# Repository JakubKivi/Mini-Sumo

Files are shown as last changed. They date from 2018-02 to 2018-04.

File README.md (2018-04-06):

# Mini-Sumo
First really project by CałkaCompany+

Oznaczenia wyjść i wejść w kodzie:

| numer wyjścia | arduino | zmienna w kodzie  | opis |
| ---  |---| ---  | ---  |
| 1 |  PWM/D3 | `floorBR` | Czujnik podłoża prawy tylny  |
| 2 | D4 | `floorFR` | Czujnik podłoża prawy przedni |
| 3\5\21 | GND | `-` | Uziemienie |
| 4\6 | VCC | `-` | Zasilanie |
| 9 |  PWM/D5 | `PWMA` | PWM dla silnika A |
| 10 |  PWM/D6 | `AIN2` | Wejście sterujące |
| 11 | D7 | `AIN1` | Wejście sterujące |
| 12 | D8 | `STBY` | |
| 13 | D9 | `BIN1` | Wejście sterujące |
| 14 | D10  | `BIN2` | Wejście sterujące |
| 15 | PWM/D11 | `PWMB` | PWM dla silnika B |
| 16 | D12  | `-` | |
| 17 | D13  | `sensorFL` | Czujnik odległości lewy przedni |
| 23 | A0 | `sensorFR` | Czujnik odległości prawy przedni|
| 24 | A1 | `sensorF` | Czujnik odległości przedni |
| 25 | A2 | `sensorBL` | Czujnik odległości prawy tylny  |
| 26 | A3 | `sensorB` | Czujnik odległości tylni |
| 27 | A4 | `-` | |
| 28 | A5 | `-` | |
| 30 |  D0/RX  | `sensorBR` |  Czujnik odległości prawy tylni |
| 31 |  D1/TX  | `floorBL` | Czujnik podłoża lewy tylny |
| 32 | D2 | `floorFL` |  Czujnik podłoża lewy przedni |

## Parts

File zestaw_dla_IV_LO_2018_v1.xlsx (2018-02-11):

typ | model | obrazek/ zdjęcie | sklep | opis | masa (g) | zagrożenie zużycia | ilość min | ilość max | cena | cena łącznie min | cena łącznie max
Komparator analogowy | Komparator analogowy LM339 - SMD |  | https://botland.com.pl/uklady-scalone-komparatory/75-komparator-analogowy-lm339-smd.html | Napięcie zasilania: 36 V lub +/- 18 V Napięcie wejściowe: -0,3 V do 36 V Obudowa: SO14 | - | wysokie | 1 | 3 | 0.50 zł | 0.50 zł | 1.50 zł
Potencjometr | Potencjometr 47kΩ leżący - SMD |  | https://botland.com.pl/potencjometry/872-potencjometr-47k-lezacy-smd.html | Potencjometr: montażowy, węglowy, leżący. Rezystancja: 47 kΩ Moc: 100 mW. Obudowa SMD. Typ: potencjometru montażowy, węglowy Moc: 100 mW Rezystancja: 47 kΩ Tolerancja: ±2 0% Charakterystyka: liniowa Wymiary korpusu: 6.5 x 6.5 x 3.6 mm Temperatura pracy: -25 do 70 st. C Kąt obrotu elektryczny: 215 ±20 st. Moment obrotowy: <2 Ncm Napięcie pracy: maks. 100 V DC Trwałość mechaniczna: 1000 cykli Standard potencjometru: 6 mm | - | niskie | 4 | 4 | 1.20 zł | 4.80 zł | 4.80 zł
Wtyk goldpin | Wtyk goldpin 1x40 prosty raster 2,54mm |  | https://botland.com.pl/gniazda-szpilkowe-goldpin/192-wtyk-goldpin-1x40-prosty-raster-254-mm.html | Listwa goldpin męska 1x40, raster 2,54 mm | - | niskie | 1 | 1 | 0.70 zł | 0.70 zł | 0.70 zł
Wtyk goldpin | Wtyk goldpin 1x40 kątowy raster 2,54mm |  | https://botland.com.pl/gniazda-szpilkowe-goldpin/205-wtyk-goldpin-1x40-katowe.html | Listwa goldpin męska 1x40, raster 2,54 mm. | - | niskie | 1 | 1 | 0.70 zł | 0.70 zł | 0.70 zł
Wtyk goldpin | Wtyk goldpin 1x40 prosty raster 2,54mm - żółty |  | https://botland.com.pl/gniazda-szpilkowe-goldpin/4167-wtyk-goldpin-1x40-prosty-raster-254-mm-zolty.html | Wtyk goldpin męski 1x40, raster 2,54 mm. Kolor żółty. | - | niskie | 1 | 1 | 0.80 zł | 0.80 zł | 0.80 zł
Wtyk goldpin | Wtyk goldpin 1x40 prosty raster 2,54mm - niebieski |  | https://botland.com.pl/gniazda-szpilkowe-goldpin/4168-wtyk-goldpin-1x40-prosty-raster-254-mm-niebieski.html | Wtyk goldpin męski 1x40, raster 2,54 mm. Kolor niebieski. | - | niske | 1 | 1 | 0.80 zł | 0.80 zł | 0.80 zł
Wtyk goldpin | Wtyk goldpin 1x40 prosty raster 2,54mm - czerwony |  | https://botland.com.pl/gniazda-szpilkowe-goldpin/4165-wtyk-goldpin-1x40-prosty-raster-254-mm-czerwony-.html | Wtyk goldpin męski 1x40, raster 2,54 mm. Kolor czerwony. | - | niske | 1 | 1 | 0.80 zł | 0.80 zł | 0.80 zł
Zestaw diod LED | Zestaw diod LED SMD 0603 - 30 szt. |  | https://botland.com.pl/zestawy-diod-led/1456-zestaw-diod-led-smd-0603-30-szt.html | W zestawie po 10 sztuk diod zielonych, żółtych i czerwonych. Zestaw 30 diod w obudowie lutowanej powierzchniowo SMD 0603. W pakiecie znajduje się: 10 diod czerwonych 10 diod żółtych 10 diod zielonych Parametry diody żółtej: Kolor: żółty Długość emitowanej fali: ok. 590 nm Jasność: 30 mcd Kąt świecenia: 140 ° Obudowa: SMD 0603 Parametry pracy: Prąd If: 20 mA Napięcie Vf: 2,0 V Parametry diody czerwonej: Kolor: czerwony Długość emitowanej fali: 625 nm Jasność: 40 mcd Kąt świecenia: 140 ° Obudowa: SMD 0603 Parametry pracy: Prąd If: 20 mA Napięcie Vf: 2,0 V Parametry diody zielonej: Kolor: zielony Długość emitowanej fali: ok. 575 nm Jasność: 30 mcd Kąt świecenia: 140 ° Obudowa: SMD 0603 Parametry pracy: Prąd If: 20 mA Napięcie Vf: 2,0 V | - | niskie | 1 | 1 | 4.90 zł | 4.90 zł | 4.90 zł
Stabilizator | Stabilizator 5V 7805CD2T - SMD TO263 |  | https://botland.com.pl/regulatory-napiecia/756-stabilizator-5v-lm7805-smd.html | Stabilizator wykorzystywany do zasilania układów logicznych zasilanych napięciem 5V. Maksymalny prąd wyjściowy to 1A. Obudowa TO263 (D2PAK). Napięcie wyjściowe: 5V Maksymalny prąd wyjściowy: 1A Maksymalne napięcie wejściowe: 35V Obudowa: TO263 (D2PAK) | - | wysokie | 1 | 3 | 1.30 zł | 1.30 zł | 3.90 zł
Stabilizator | Stabilizator 5V L7805CV - THT TO220 |  | https://botland.com.pl/regulatory-napiecia/3092-stabilizator-5v-l7805cv-tht-to220.html | Stabilizator wykorzystywany do zasilania układów logicznych zasilanych napięciem 5 V. Maksymalny prąd wyjściowy to 1,5 A. Symbol: LM7805 Napięcie wyjściowe: 5 V ( z dokładnością do 2 %) Maksymalny prąd wyjściowy: 1,5 A Maksymalne napięcie wejściowe: 35 V Obudowa: TO-220 | - | wysokie | 1 | 3 | 0.90 zł | 0.90 zł | 2.70 zł
Kondensator ceramiczny | Zestaw kondensatorów ceramicznych 0805 190szt. |  | http://allegro.pl/zestaw-kondensatorow-ceramicznych-0805-190szt-i6819067595.html | Zestaw kondensatorów SMD 0805. W skład zestawu wchodzi 19 wartości w listkach po 10 sztuk każdej od 22 pF do 1000 nF | - | niskie | 1 | 1 | 11.99 zł | 11.99 zł | 11.99 zł
Mikrokontroler AVR | Mikrokontroler AVR - ATmega328P-AU SMD |  | https://botland.com.pl/avr-w-obudowie-smd/1836-mikrokontroler-avr-atmega328p-au-smd.html | Mikrokontroler z rodziny AVR firmy Atmel w obudowie lutowanej powierzchniowo (SMD. Został wykorzystany w popularnym module Arduino Pro.)Zasilanie: 1,8 V - 5,5 V Taktowanie: do 20MHz Pamięć Flash: 32KB 23 linie wyjścia/wejścia Dwa 8-bitowe liczniki Jeden 16-bitowy licznik 6 kanałów PWM 6 kanałów 10-bitowego przetwornika analogowo-cyfrowego Sprzętowe interfejsy komunikacyjne: USART, SPI, TWI (I2C) Obudowa SMD - TQF P32 | - | wysokie | 1 | 3 | 8.90 zł | 8.90 zł | 26.70 zł
Mikrokontroler AVR | Mikrokontroler AVR - ATmega328P-PU DIP |  | https://botland.com.pl/avr-tht-dip/1264-mikrokontroler-avr-atmega328p-pu-dip.html | Mikrokontroler z rodziny AVR firmy Atmel w obudowie przewlekanej (DIP). Został wykorzystany w popularnym module Arduino Uno.Zasilanie: 1,8 V - 5,5 V Taktowanie: do 20 MHz Pamięć Flash: 32 KB 23 linie wyjścia/wejścia Dwa 8-bitowe liczniki Jeden 16-bitowy licznik 6 kanałów PWM 6 kanałów 10-bitowego przetwornika analogowo-cyfrowego Sprzętowe interfejsy komunikacyjne: USART, SPI, TWI (I2C) Obudowa DIP | - | wysokie | 1 | 3 | 10.90 zł | 10.90 zł | 32.70 zł
Podstawka do układów DIP 28 pin wąska - 5 szt. | Podstawka do układów DIP 28 pin wąska - 5 szt. |  | https://botland.com.pl/podstawki-pod-uklady-scalone/90-podstawka-do-ukladow-dip-28pin-waska-5szt.html | Podstawka pod układ scalony DIP 28. Cena za 5 sztuk. | - | niskie | 1 | 1 | 2 zł | 2.00 zł | 2.00 zł
rezystory | Zestaw rezystorów SMD 0805 - 1500szt. |  | https://botland.com.pl/zestawy-rezystorow/536-zestaw-rezystorow-smd-0805-2500-szt.html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 | Zbiór 30 popularnych wartości rezystorów o tolerancji 5 % w obudowach SMD 0805, przydatnych w warsztacie zarówno robotyka jak i elektronika. Rezystory są zapakowane w osobne, opisane torebki strunowe. Całość znajduje się w kartonowym pudełku, ułatwiającym przechowywanie. | - | niskie | 1 | 1 | 23.90 zł | 23.90 zł | 23.90 zł
czujniki odległości | Pololu - cyfrowy czujnik odległości IR 38kHz - 60cm |  | https://botland.com.pl/cyfrowe-czujniki-odleglosci/7622-pololu-cyfrowy-czujnik-odleglosci-ir-38khz-60cm.html | Napięcie zasilania: od 3,3 V do 5 V Pobór prądu: 16 mA Układ: TSSP77038 Częstotliwość próbkowania: 1 kHz Zasięg: do 60 cm Wymiary: 15 x 10 x 5 mm Masa: 0,6 g | - | średnie | 6 | 8 | 28.41 zł | 170.46 zł | 227.28 zł
Czujnik podłoża | Czujnik transoptor odbiciowy CNY70 |  | https://botland.com.pl/transoptory-odbiciowe/52-czujnik-transoptor-odbiciowy-cny70.html | Transoptor odbiciowy, stosowany np. do odróżniania krawędzi lub wykrywania linii. Wymiary obudowy to 7 x 7 x 6 mm, montaż przewlekany. Napięcie zasilania diody: 5 V Maksymalny prąd diody: 50 mA Maksymalne napięcie kolektor-emiter: 32 V Maksymalny prąd kolektora: 50 mA | - | średnie | 10 | 12 | 2.66 zł | 26.60 zł | 31.92 zł
silniki | Silnik Pololu MP 10:1 |  | https://botland.com.pl/medium-power-mp-/4063-silnik-pololu-mp-101.html | Napięcie zasilania:3 V - 9 V Prąd bez obciążenia (6 V):40 mA Prąd przy zatrzymanym wale (6 V):700 mA Prędkość bez obciążenia (6 V):2200 obr/min Moment obrotowy (6 V):0,2 kg*cm (0,010 Nm) Przełożenie:9.96:1 Średnica wału:3 mm Wymiary korpusu:24 x 10 x 12 mm Masa:10 g Obustronny wał:NIE | 40 | wysokie | 4 | 6 | 61.66 zł | 246.64 zł | 369.96 zł
sterownik silników | TB6612FNG - dwukanałowy sterownik silników |  | https://botland.com.pl/sterowniki-silnikow-dc/495-tb6612fng-dwukanalowy-sterownik-silnikow-.html | Dwukanałowy mostek H. Ciągły prąd na kanał 1,2 A chwilowy do 3,2 A. Napięcie zasilania do 15 V. Obudowa SSOP-24 (SMD).Maksymalne napięcie zasilania silników: 4,5 - 15 V Prąd ciągły 1,2 A Prąd chwilowy: 3,2 A Tryb niskiego poboru prądu (Standby) Możliwość zmiany kierunku obrotów silnika Możliwość szybkiego zatrzymania silnika Obudowa: SMD SSOP24 Kanały sterownika można połączyć aby otrzymać większą wydajność prądową | - | wysokie | 1 | 3 | 8.90 zł | 8.90 zł | 26.70 zł
akumulator | Pakiet Li-Pol Dualsky 800mAh 25C 2S 7.4V ECO-S |  | https://botland.com.pl/akumulatory-li-pol-2s-74v-/2393-pakiet-lipol-dualsky-800mah-25c-2s-74v-eco-s.html | Wydajny akumulator litowo-polimerowy Dualsky. Prąd rozładowania: ciągły 25 C (20 A). Wymiary 66 x 26 x 13,5 mm. Masa: 43 g.Parametry Dwa ogniwa (2S) Li-pol Producent: Dualsky, seria ES Napięcie nominalne: 7,4 V Pojemność: 800 mAh Prąd rozładowania ciągły: 25 C (20A) Wyjście balansera Przewody: 20AWG Zamontowany konektor - wtyk JST Wymiary: 66 x 26 x 13,5 mm Masa: 43 g | 43 | wysokie | 2 | 3 | 24.90 zł | 49.80 zł | 74.70 zł
Przewody połączeniowe | Przewody połączeniowe żeńsko-męskie 20cm - 40szt |  | https://botland.com.pl/przewody-polaczeniowe/1067-przewody-polaczeniowe-zesko-meskie-20cm-40szt.html | Zestaw zawiera 40 szt. różnokolorowych przewodów połączeniowych o długości 20 cm zakończonych z jednej strony złączem żeńskim, z drugiej końcówką męska.Zestaw zawiera 40 szt różnokolorowych przewodów połączeniowych o długości 20 cm. Zakończone są z jednej strony złączem żeńskim, z drugiej końcówką męska. Przewody można rozdzielać na pojedyncze sztuki. Przewody doskonale nadają się do łączenia pól na płytkach stykowych i w zestawach (np.: Arduino lub STM32Discovery). Długość przewodu 20cm. | - | niskie | 1 | 1 | 5.99 zł | 5.99 zł | 5.99 zł
Przewody połączeniowe | Przewody połączeniowe męsko-męskie 20cm - 40szt. |  | https://botland.com.pl/przewody-polaczeniowe/1223-przewody-polaczeniowe-mesko-meskie-20cm-40szt.html | Zestaw zawiera 40 szt. różnokolorowych przewodów połączeniowych o długości 20 cm. Zakończone są z obu stron złączem męskim typu goldpin. Przewody można rozdzielać na pojedyncze sztuki. doskonale nadają się do łączenia pól na płytkach stykowychi zestawach uruchomieniowych (np. Arduino, STM32Discovery). Długość przewodu to 20 cm. | - | niskie | 1 | 1 | 5.95 zł | 5.95 zł | 5.95 zł
Kondensator elektrolityczny | Kondensator elektrolityczny 100uF/16V SMD - 5 szt. |  | https://botland.com.pl/kondensatory-/257-kondensator-elektrolityczny-100uf16v-smd-5-szt.html | Kondensator elektrolityczny SMD, pojemność: 100 uF, napięcie maksymalne: 16 V, temperatura pracy maksymalna: 85 °C. Cena za 5 szt. Pojemność: 100 uF Napięcie maksymalne: 16V Rozmiar: Ø 6,3 x 5,3 mm Tolerancja ±20 % Temperatura pracy: maks. 85°C | - | niskie | 1 | 1 | 2.50 zł | 2.50 zł | 2.50 zł
Rezonator kwarcowy | Rezonator kwarcowy 16MHz - UC49 - SMD - niski |  | https://botland.com.pl/rezonatory/308-rezonator-kwarcowy-16mhz-uc49-smd-niski.html |  | - | niskie | 2 | 2 | 0.80 zł | 1.60 zł | 1.60 zł
razem |  |  |  | RAZEM: |  |  |  |  |  | 592.33 zł | 865.49 zł

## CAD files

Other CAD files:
ZabawaKiviego.blend

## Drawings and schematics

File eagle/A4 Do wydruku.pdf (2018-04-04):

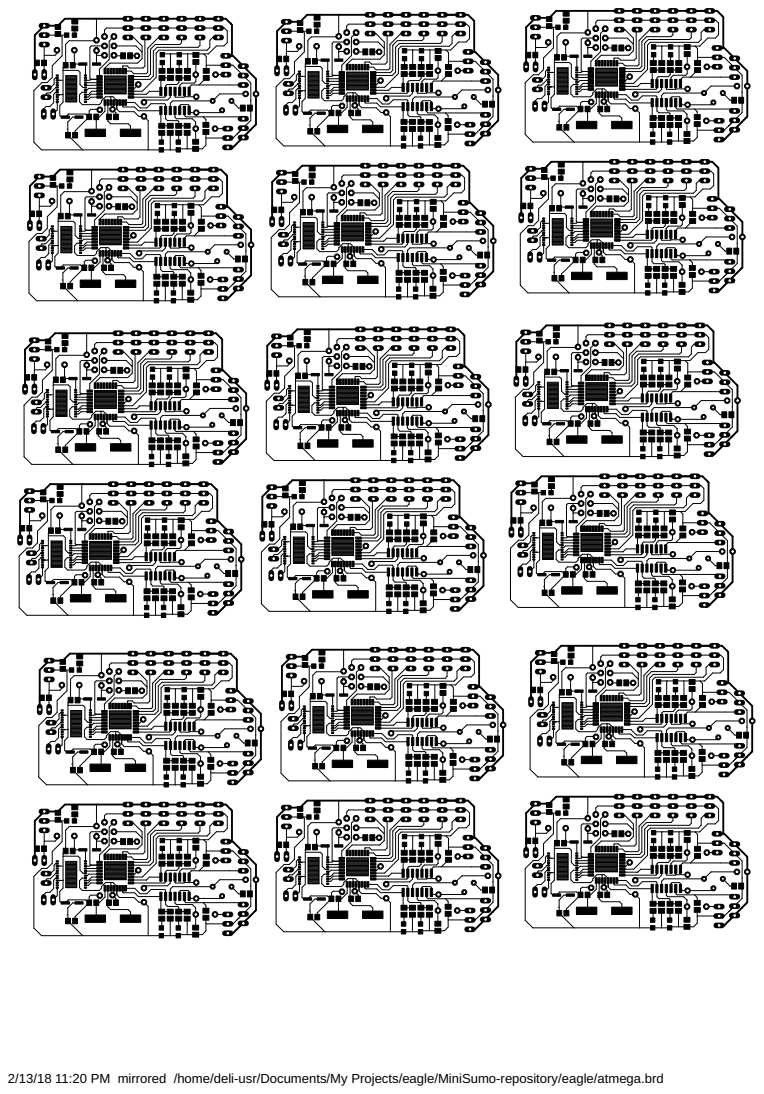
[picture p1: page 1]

2/13/18 11:20 PM mirrored /home/deli-usr/Documents/My Projects/eagle/MiniSumo-repository/eagle/atmega.brd

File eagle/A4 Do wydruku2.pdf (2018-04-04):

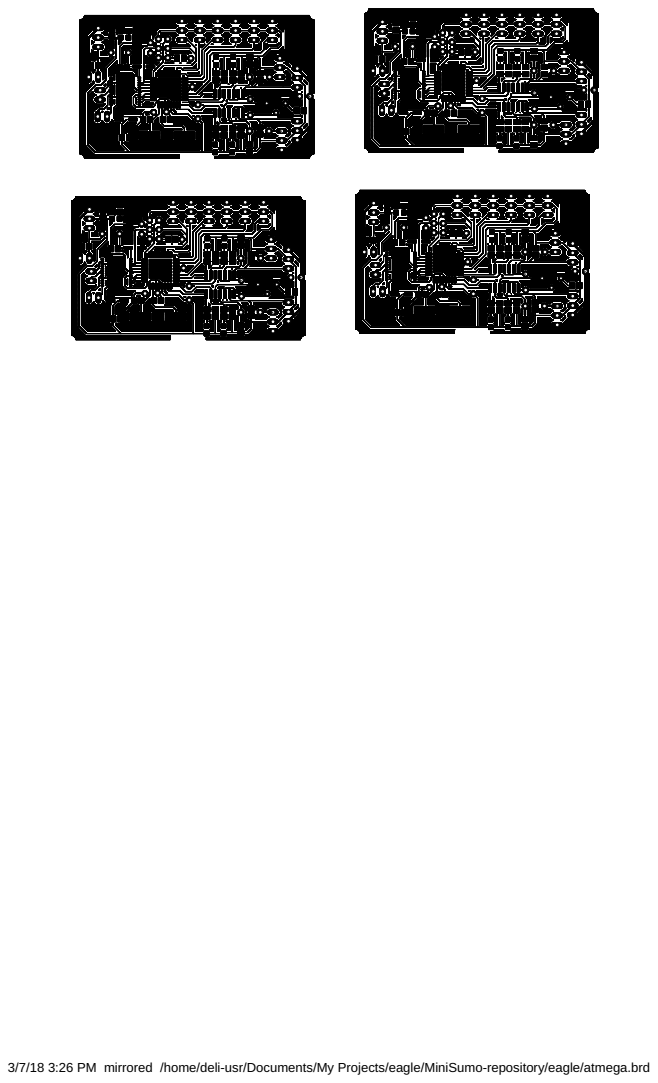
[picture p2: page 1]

3/7/18 3:26 PM mirrored /home/deli-usr/Documents/My Projects/eagle/MiniSumo-repository/eagle/atmega.brd

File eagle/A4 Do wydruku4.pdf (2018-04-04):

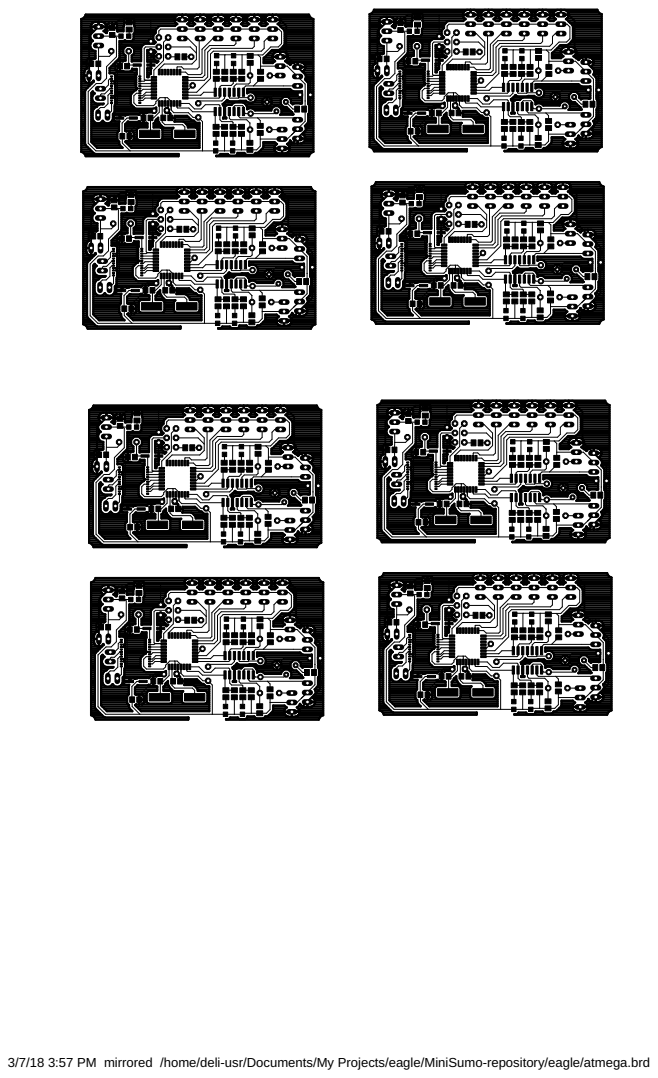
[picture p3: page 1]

3/7/18 3:57 PM mirrored /home/deli-usr/Documents/My Projects/eagle/MiniSumo-repository/eagle/atmega.brd

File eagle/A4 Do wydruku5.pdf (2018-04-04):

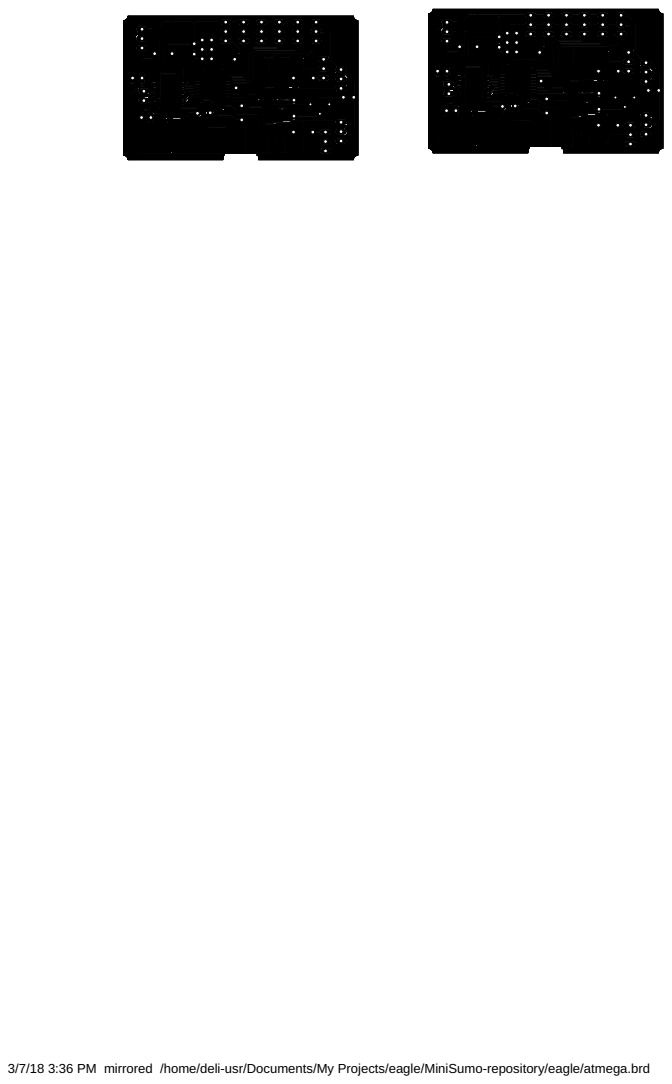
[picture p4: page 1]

3/7/18 3:36 PM mirrored /home/deli-usr/Documents/My Projects/eagle/MiniSumo-repository/eagle/atmega.brd

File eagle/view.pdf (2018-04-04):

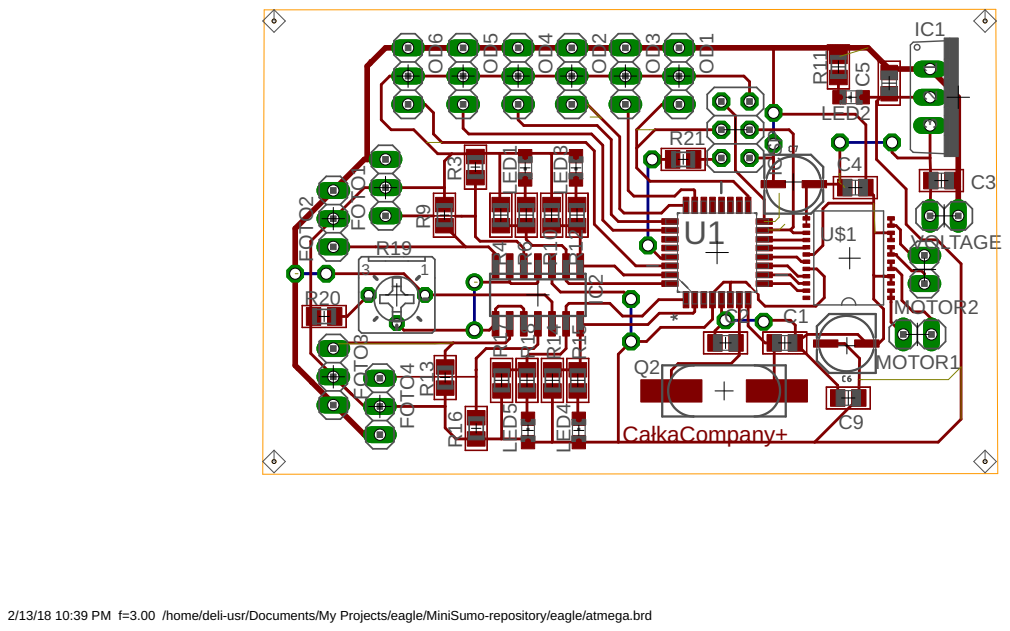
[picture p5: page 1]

2/13/18 10:39 PM f=3.00 /home/deli-usr/Documents/My Projects/eagle/MiniSumo-repository/eagle/atmega.brd

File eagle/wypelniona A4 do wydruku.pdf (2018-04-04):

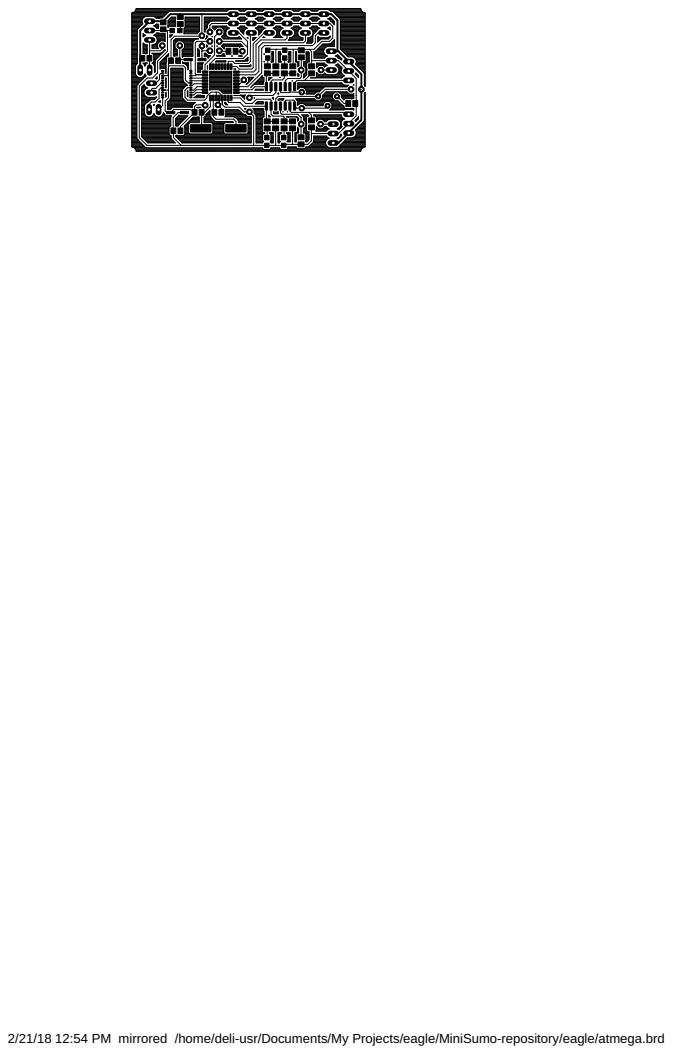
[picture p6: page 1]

2/21/18 12:54 PM mirrored /home/deli-usr/Documents/My Projects/eagle/MiniSumo-repository/eagle/atmega.brd

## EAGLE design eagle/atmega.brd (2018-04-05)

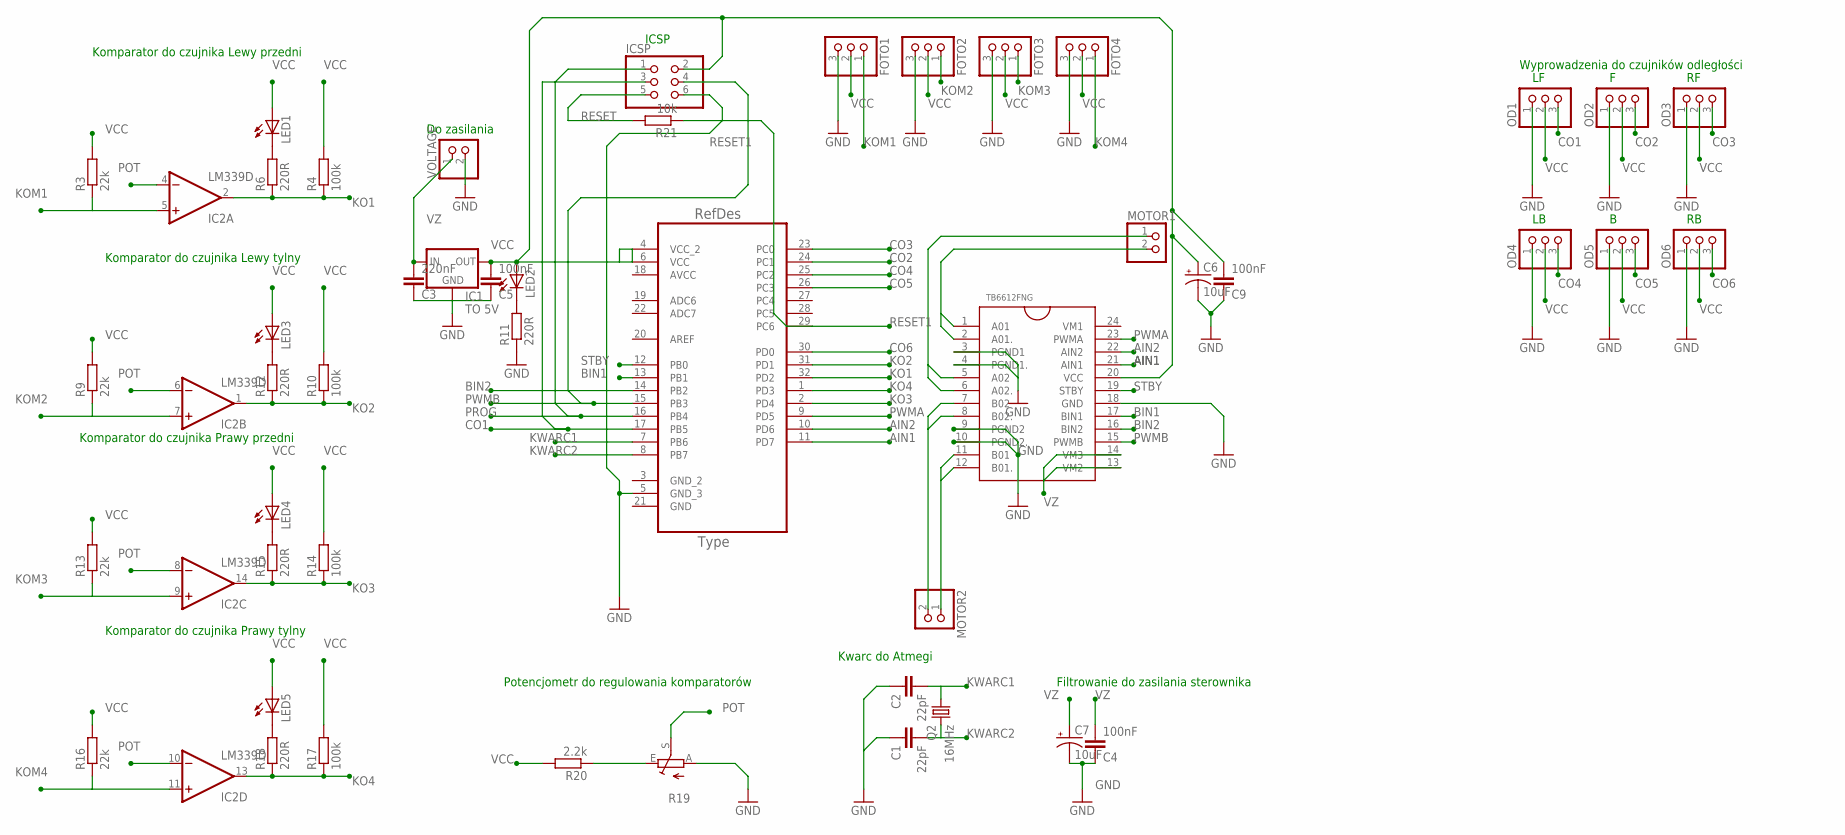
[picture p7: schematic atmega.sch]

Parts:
C1, C2: 22pF; C0805
C3: 220nF; C0805
C4, C5, C9: 100nF; C0805
C6, C7: 10uF; PANASONIC_C
FOTO1, FOTO2, FOTO3, FOTO4: PINHD-1X3; 1X03
IC1: TO 5V; TO220V
IC2: LM339D; SO14
ICSP: PINHD-2X3; 2X03
LED1, LED2, LED3, LED4, LED5: LEDCHIPLED_0805; CHIPLED_0805
MOTOR1, MOTOR2: PINHD-1X2; 1X02
OD1, OD2, OD3, OD4, OD5, OD6: PINHD-1X3; 1X03
Q2: 16MHz; CSM-7X-DU
R3, R9, R13, R16: 22k; M0805
R4, R10, R14, R17: 100k; M0805
R6, R11, R12, R15, R18: 220R; M0805
R19: TRIM_EU-B25P; B25P
R20: 2.2k; M0805
R21: 10k; M0805
U1: ATMEGA328P-AU; QFP80P900X900X120-32N
U$1: TB6612FNG; SSOP24
VOLTAGE: PINHD-1X2; 1X02

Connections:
AIN1: U1.11 (PD7), U$1.21 (AIN1)
AIN2: U1.10 (PD6), U$1.22 (AIN2)
AVCC: U1.18 (AVCC)
BIN1: U1.13 (PB1), U$1.17 (BIN1)
BIN2: U1.14 (PB2), U$1.16 (BIN2)
CO1: ICSP.3, OD1.3, U1.17 (PB5)
CO2: OD2.3, U1.24 (PC1)
CO3: OD3.3, U1.23 (PC0)
CO4: OD4.3, U1.25 (PC2)
CO5: OD5.3, U1.26 (PC3)
CO6: OD6.3, U1.30 (PD0)
GND: C1.1, C2.1, C3.1, C4.1, C5.1, C6.-, C7.-, C9.1, FOTO1.3, FOTO2.3, FOTO3.3, FOTO4.3, IC1.1 (GND), IC2.12 (GND), ICSP.6, OD1.1, OD2.1, OD3.1, OD4.1, OD5.1, OD6.1, R11.1, R19.A, U1.5 (GND_3), U$1.3 (PGND1), U$1.4 (PGND1.), U$1.9 (PGND2), U$1.10 (PGND2.), U$1.18 (GND), VOLTAGE.2
KO1: IC2.2 (OUT), R4.1, R6.1, U1.32 (PD2)
KO2: IC2.1 (OUT), R10.1, R12.1, U1.31 (PD1)
KO3: IC2.14 (OUT), R14.1, R15.1, U1.2 (PD4)
KO4: IC2.13 (OUT), R17.1, R18.1, U1.1 (PD3)
KOM1: FOTO1.1, IC2.5 (+IN), R3.1
KOM2: FOTO2.1, IC2.7 (+IN), R9.1
KOM3: FOTO3.1, IC2.9 (+IN), R13.1
KOM4: FOTO4.1, IC2.11 (+IN), R16.1
KWARC1: C2.2, Q2.1, U1.7 (PB6)
KWARC2: C1.2, Q2.2, U1.8 (PB7)
unnamed: LED3.C, R12.2
unnamed: R19.E, R20.1
unnamed: LED2.C, R11.2
unnamed: LED1.C, R6.2
unnamed: LED4.C, R15.2
unnamed: LED5.C, R18.2
OUTMA1: MOTOR1.2, U$1.1 (A01), U$1.2 (A01.)
OUTMA2: MOTOR1.1, U$1.5 (A02), U$1.6 (A02.)
OUTMB1: MOTOR2.1, U$1.11 (B01), U$1.12 (B01.)
OUTMB2: MOTOR2.2, U$1.7 (B02), U$1.8 (B02.)
POT: IC2.4 (-IN), IC2.6 (-IN), IC2.8 (-IN), IC2.10 (-IN), R19.S
PROG: ICSP.1, U1.16 (PB4)
PWMA: U1.9 (PD5), U$1.23 (PWMA)
PWMB: ICSP.4, U1.15 (PB3), U$1.15 (PWMB)
RESET: ICSP.5, R21.2
RESET1: R21.1, U1.29 (PC6)
STBY: U1.12 (PB0), U$1.19 (STBY)
VCC: C5.2, C6.+, C9.2, FOTO1.2, FOTO2.2, FOTO3.2, FOTO4.2, IC1.2 (OUT), IC2.3 (V+), ICSP.2, LED1.A, LED2.A, LED3.A, LED4.A, LED5.A, OD1.2, OD2.2, OD3.2, OD4.2, OD5.2, OD6.2, R3.2, R4.2, R9.2, R10.2, R13.2, R14.2, R16.2, R17.2, R20.2, U1.4 (VCC_2), U1.6 (VCC), U$1.20 (VCC)
VZ: C3.2, C4.2, C7.+, IC1.3 (IN), U$1.13 (VM2), U$1.14 (VM3), VOLTAGE.1

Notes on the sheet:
Kwarc do Atmegi
Filtrowanie do zasilania sterownika
Komparator do czujnika Lewy przedni
Komparator do czujnika Lewy tylny
Komparator do czujnika Prawy tylny
Komparator do czujnika Prawy przedni
ICSP
Potencjometr do regulowania komparatorów
Do zasilania
Wyprowadzenia do czujników odległości

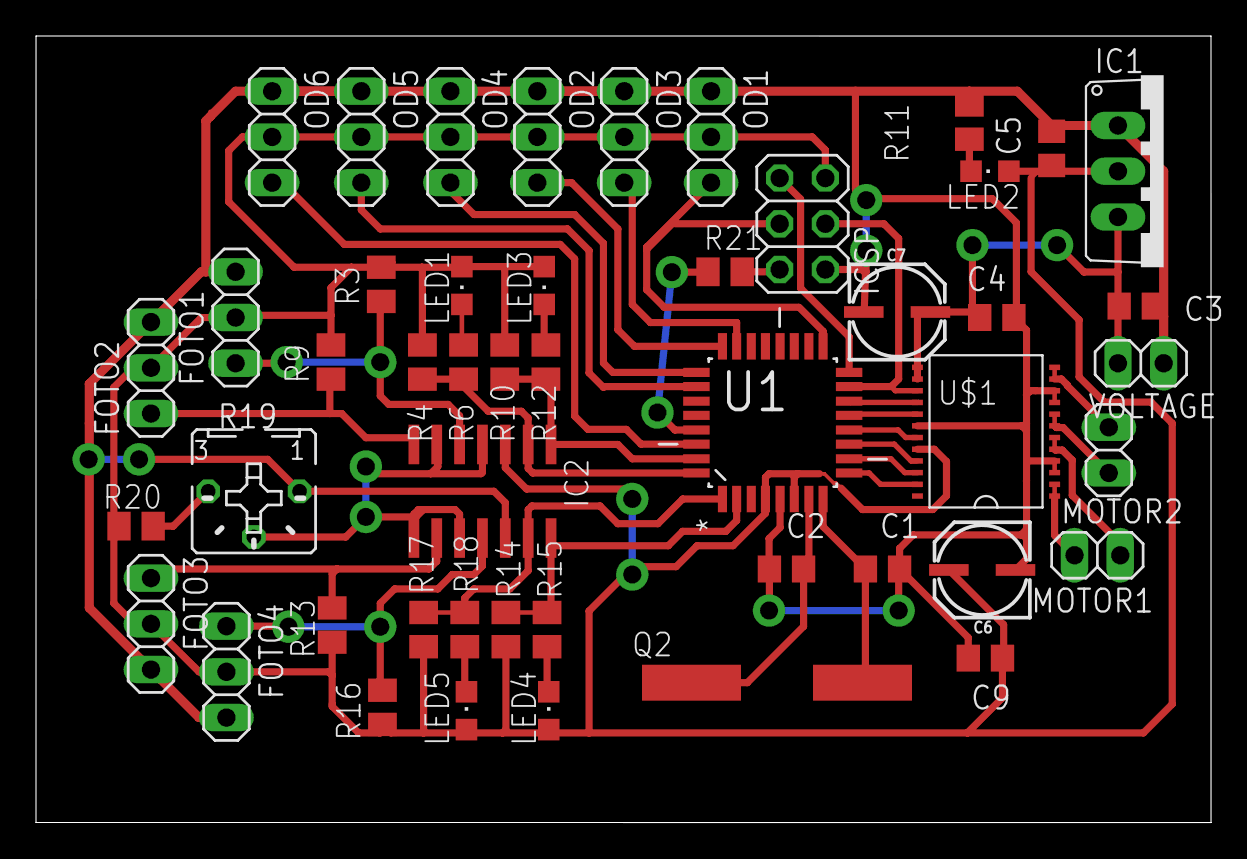
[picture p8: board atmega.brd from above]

Board: 2 copper layers, 65.3 x 43.7 mm, 48 parts (0 on the bottom side), 40 nets.

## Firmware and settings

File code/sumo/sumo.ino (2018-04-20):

#include "header.h"

void setup(){
	//czujniki podłogowe
	pinMode(floorFL, INPUT);
	pinMode(floorFR, INPUT);
	pinMode(floorBL, INPUT);
	pinMode(floorBR, INPUT);

	//czujniki odległości
	pinMode(sensorF, INPUT);
	pinMode(sensorFL, INPUT);
	pinMode(sensorFR, INPUT);
	pinMode(sensorB, INPUT);
	pinMode(sensorBR, INPUT);
	pinMode(sensorBL, INPUT);

	//silnik
	pinMode(AIN1, OUTPUT);
	pinMode(AIN2, OUTPUT);
	pinMode(BIN1, OUTPUT);
	pinMode(BIN2, OUTPUT);
	pinMode(PWMA, OUTPUT);
	pinMode(PWMB, OUTPUT);
}

void loop(){
	if(!touchFloor){													//jeżeli nie dotykasz krawędzi
		if(seeEnemieNotFront()){													//jeśli nie widzisz przeciwnika
			toSeeEnemyFront();    
		}else if(seeEnemy()){ 		//jeżeli widać go z przodu bądź tyłu
			go();		
		}else //wogóle nie mam pojęcia gdzie jest ziomek przeciwnik
      goRandomly();
	}else{  //jak jestem na liniiii
		//zmiana kierunku
		if(direction) direction = false;
		else direction = true;
    outOfLine();
    //zrobić coś żeby nie było akcji że jedzie wzdłóż linii (np skręć zależy)
	}
}

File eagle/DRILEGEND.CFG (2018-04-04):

InputUserCfg = 1
SymbolLayer = 144
SymbolSize = 40
SymbolWidth = 4
TextSize = 50.0000
TextRatio = 5
IdxFnt = 0
decMM = 2
decMIL = 0
SortHoles = 1
TolPlated = 0.02
TolNonPlated = 0.03
PlatedStatusNot = NOT
PlatedStatusBoth = BOTH
PlatedStatusYes = YES
VerticalChart = 1
HighCellFactor = 1.10
WideCellFactor = 1.10
CellOutline = 4
TitleOutline = 4
TableOutline = 8
SymbTitle = Sym
ToolTitle = N°
MMTitle = MM
MilTitle = Mils
MicTitle = Mic
QtyTitle = Qty
TypeTitle = Plated
ToleTitle = Tol
SymbRank = 1
ToolRank = 2
MMRank = 4
MilRank = 3
MicRank = 0
QtyRank = 5
TypeRank = 6
ToleRank = 0
OutputDrillRack = 0
DrillRackFile = DRILLRACK.DRL
Unit = 0
OutputUserCfg = 1
UserCfgFile = DRILEGEND.CFG

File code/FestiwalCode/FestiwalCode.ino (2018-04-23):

const int F = 2;
const int FR = 1;
const int FL = 7;
const int B = 0;

void setup() {
  
  pinMode(10, OUTPUT);
  pinMode(11, OUTPUT);
  pinMode(12, OUTPUT);
  pinMode(13, OUTPUT);
  pinMode(5, OUTPUT);
  pinMode(6, OUTPUT);
}

void loop() {
   if(digitalRead(1)==HIGH){
      digitalWrite(10, LOW);
      digitalWrite(11, LOW);
      digitalWrite(12, LOW);
      digitalWrite(13, LOW);
   }else{
        digitalWrite(10, LOW);
        digitalWrite(11, HIGH);
        digitalWrite(12, LOW);
        digitalWrite(13, HIGH);
   }

   if(digitalRead(2)==HIGH){
      digitalWrite(10, LOW);
      digitalWrite(11, LOW);
      digitalWrite(12, LOW);
      digitalWrite(13, LOW);
   }else{
        digitalWrite(10, HIGH);
        digitalWrite(11, LOW);
        digitalWrite(12, HIGH);
        digitalWrite(13, LOW);
   }

   /*if(digitalRead(7)==HIGH){
      digitalWrite(10, LOW);
      digitalWrite(11, LOW);
      digitalWrite(12, LOW);
      digitalWrite(13, LOW);
   }else{
        digitalWrite(10, LOW);
        digitalWrite(11, HIGH);
        digitalWrite(12, HIGH);
        digitalWrite(13, LOW);
   }*/
   
   /*if(digitalRead(7)==HIGH){
      digitalWrite(10, LOW);
      digitalWrite(11, LOW);
      digitalWrite(12, LOW);
      digitalWrite(13, LOW);
   }else{
        digitalWrite(10, LOW);
        digitalWrite(11, HIGH);
        digitalWrite(12, HIGH);
        digitalWrite(13, LOW);
   }*/
   
   /*if(digitalRead(2)==HIGH){
      do{
      digitalWrite(10, LOW);
      digitalWrite(11, HIGH);
      digitalWrite(12, HIGH);
      digitalWrite(13, LOW);
      }while(digitalRead(0));
   }*/
}

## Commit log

2018-02-04 Początek projektu płytki PCB.
    [DRILEGEND.CFG, atmega.sch]
2018-02-06 Ładniej wygląda, dodałem transobtor zamiast fotorezystorów. Podłączenie komparatorów
    [atmega.sch]
2018-02-06 zmiana pinów ICSP (programowanie) z 6x1 na 2x3
    [atmega.sch]
2018-02-06 zmiana pinów wychodzący (silniki) piny na czujniki, skończone podłączanie elementów.
    [atmega.sch]
2018-02-07 Zmiany podłączenia. Rozpoczęgie pracy nad płyką PCB.
    [atmega.brd, atmega.sch]
2018-02-08 Przygotowywanie do zmiany procesora.
    [atmega.sch]
2018-02-09 Dodanie arkusza z listą zakupów.
    [zestaw_dla_IV_LO_2018_v1.xlsx]
2018-02-09 Dodanie mini USB. Dodaj rezystory przed USB, podmień obudowy rezystorów.
    [atmega.brd, atmega.sch]
2018-02-10 Arkusz nieskończony
    aha
    [zestaw_dla_IV_LO_2018_v1.xlsx]
2018-02-10 Dodano zużycie do kondensatorów
    [zestaw_dla_IV_LO_2018_v1.xlsx]
2018-02-11 Podłączenie USB, Początek podłączania do sterownika.
    [atmega.brd, atmega.sch]
2018-02-11 do sprawdzenia czy wszystko dobrze
    [zestaw_dla_IV_LO_2018_v1.xlsx]
2018-02-11 Usunąłem ATmega32U
    [atmega.brd, atmega.sch]
2018-02-11 ostateczne sprawdzenie' git push origin master git status
    [zestaw_dla_IV_LO_2018_v1.xlsx]
2018-02-11 Podłączenie wszystkiego zakończone, wystarczy tylko obawić się nad estetyką
    [DRILEGEND.CFG, atmega.brd, atmega.sch]
2018-02-13 zapomiałem co się działo
    [atmega.brd]
2018-02-13 Dodano pliki do wydruku i podglądu
    [atmega.sch]
2018-02-25 Zabawa Blenderem że aż mi się ostrza stępiły
    [ZabawaKiviego.blend]
2018-03-01 poprawnienie płytki
    [atmega.brd, atmega.sch]
2018-03-04 dodano rysunek techniczny
    [atmega.brd, rysunek techniczny.brd]
2018-03-07 Do wydruku wszystko
    [atmega.brd]
2018-03-07 Dodano napis na pcb
    [atmega.brd]
2018-03-18 Gotowa do wysyłki
    [atmega.brd]
2018-03-22 Pogrubienie ścieżek
    [atmega.brd]
2018-03-23 Poprawienie przelotek
    [atmega.brd]
2018-03-28 Przelotkę w końcu zrobiłem dobrze ale muszę dokończyć
    na infie
    [atmega.brd]
2018-03-28 Ogrubienie przelotek
    [atmega.brd]
2018-03-29 Usunięcie zwarć
    [atmega.brd]
2018-03-29 Przesunięcie napisu ze ścierzek
    [atmega.brd]
2018-03-29 Usunięcie śmietnika i dodanie napisu
    [atmega.brd]
2018-03-29 Napraawiłem
    [atmega.brd]
2018-04-05 Dopisanie kilku komentarzy do schematu
    [atmega.brd, atmega.sch]

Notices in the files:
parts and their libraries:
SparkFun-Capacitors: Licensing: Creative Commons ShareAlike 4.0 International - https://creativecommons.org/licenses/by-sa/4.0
